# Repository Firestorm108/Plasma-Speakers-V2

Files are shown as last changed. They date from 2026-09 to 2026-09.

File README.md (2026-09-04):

# Plasma-Speakers-V2

Dual flyback transformers that produce audio through the modulation of high frequency plasma arcs.

# What is it?
This is version two of my plasma speaker project (https://github.com/Firestorm108/Stereo-Plasma-Speaker). It produces arcs much larger than the previous version, and the heating of the MOSFETs is much lower. This is because it sort of combines two types of oscillating technologies. It uses the same principle of a ZVS driver, switching at zero volts for a great efficiency, but it is able to do this digitally instead of through analog components.

# Images

Screenshot 2026-09-03 at 11 55 16 PM

Screenshot 2026-09-03 at 11 56 20 PM

Screenshot 2026-09-04 at 12 08 57 AM
Screenshot 2026-09-04 at 12 09 14 AM

| Item | Price | Link |
| --- | ---: | --- |
| PCB + Assembly | $170 | JLCPCB |
| IRFP460 MOSFETs | $12 | [Amazon](https://www.amazon.com/ACEIRMC-Transistors-IRFP260N-N-Channel-IRFP260NPBF/dp/B0CGHP2LH6) |
| AC Cable | $7 | [Amazon](https://www.amazon.com/Standard-Electronics-Computer-Printer-Monitor/dp/B09VRLJD7J/) |
| 25A 24V PSU | N/A | Already Owned |
| Flyback Transformers (2) | $50 | [Amazon](https://www.amazon.com/TEAMWILL-Transformer-BSC24-39202-BSC26-N2137-BSC26-N2138/dp/B09P2Y9X9F/) |
| **Total** | **$239** | |

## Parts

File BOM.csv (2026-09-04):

Item | Price | Link
PCB + Assembly | $170 | JLCPCB
IRFP460 MOSFETs | $12 | https://www.amazon.com/ACEIRMC-Transistors-IRFP260N-N-Channel-IRFP260NPBF/dp/B0CGHP2LH6
AC Cable | $7 | https://www.amazon.com/Standard-Electronics-Computer-Printer-Monitor/dp/B09VRLJD7J/
25A 24V PSU | N/A | Already Owned
Flyback Transformers (2) | $50 | https://www.amazon.com/TEAMWILL-Transformer-BSC24-39202-BSC26-N2137-BSC26-N2138/dp/B09P2Y9X9F/
Total: | $239

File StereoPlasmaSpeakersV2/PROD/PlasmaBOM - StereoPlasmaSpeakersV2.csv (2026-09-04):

Id | Designator | Footprint | Quantity | Comment | Supplier and ref
1 | AV1, AV2 | CONN-TH_AV-5 | 2 | AV-5
2 | C1 | C_1206_3216Metric | 1 | 47uF
3 | C2, C3, C6, C7 | C_1206_3216Metric | 4 | 10uF
4 | C4, C8 | C_1206_3216Metric | 2 | 100nF
5 | C5, C9, C11, C14 | C_1206_3216Metric | 4 | 10nF
6 | C10, C13 | C_1206_3216Metric | 2 | 4.7nF
7 | C12, C15 | C_1206_3216Metric | 2 | 1uF
8 | C17, C18, C19, C20, C21, C22 | CAP-TH_L12.0-W6.0-P10.00-D0.6-A | 6 | C322J10458P40001
9 | D1, D2, D3 | LED_1206_3216Metric | 3 | LED
10 | D4, D5 | D_SOD-123 | 2 | 1N4148W
11 | J1 | CONN-TH_P10.16_KF135T-10.16-2P | 1 | 24V 25A
12 | J2 | CONN-TH_P10.16_KF135T-10.16-2P | 1 | Primary_1
13 | J3 | CONN-TH_P10.16_KF135T-10.16-2P | 1 | Primary_2
14 | Q2, Q4 | TO-247-3_Vertical | 2 | IRFP260N
15 | Q3, Q5 | SOT-89-3 | 2 | BCX51
16 | R1 | R_1206_3216Metric | 1 | 2.2K
17 | R2, R9, R11, R17, R20, R23 | R_1206_3216Metric | 6 | 1K
18 | R3, R10, R25, R27 | R_1206_3216Metric | 4 | 470
19 | R4, R6, R13, R14 | R_1206_3216Metric | 4 | 100
20 | R5, R8, R12, R15 | R_1206_3216Metric | 4 | 10K
21 | R7, R16 | R_1206_3216Metric | 2 | 220
22 | R18, R21 | R_1206_3216Metric | 2 | 33K
23 | R19, R22 | R_1206_3216Metric | 2 | 3.3K
24 | R24, R26 | R_1206_3216Metric | 2 | 270
25 | RV1, RV2 | RES-ADJ-TH_3296W | 2 | 5K
26 | SW1, SW2 | SW_Push_SPST_NO_Alps_SKRK | 2 | Test
27 | U1 | TO-263-3_L8.6-W10.2-P2.54-LS14.4-BR | 1 | LM7812SX/NOPB
28 | U2, U3 | SOIC-8_L5.0-W4.0-P1.27-LS6.0-BL | 2 | LM311
29 | U4, U5 | SOIC-8_3.9x4.9mm_P1.27mm | 2 | NE555D

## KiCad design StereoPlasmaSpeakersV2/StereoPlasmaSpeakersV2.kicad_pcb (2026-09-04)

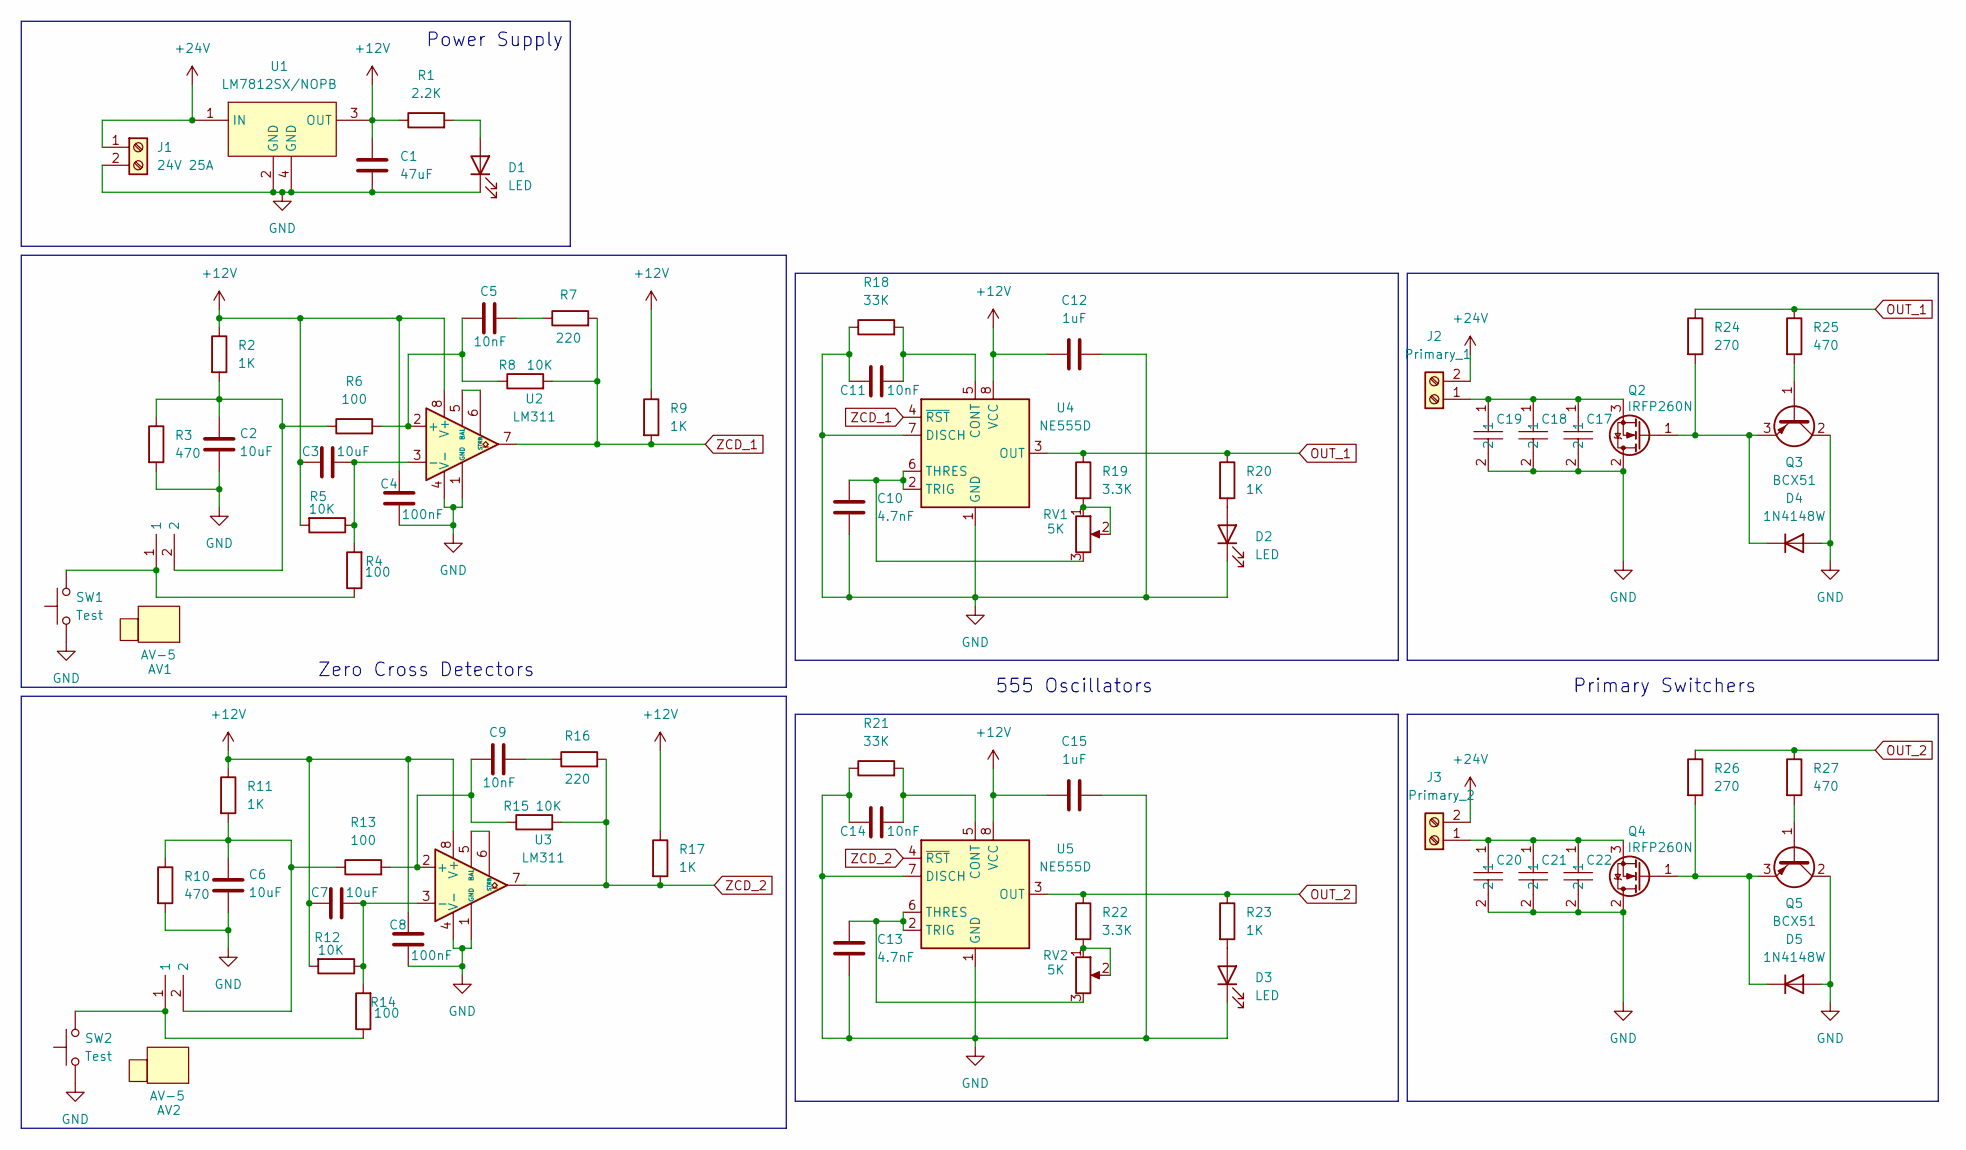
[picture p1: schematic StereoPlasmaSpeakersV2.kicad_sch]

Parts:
AV1, AV2: AV-5; CONN-TH_AV-5; MPN AV-5; LCSC Part C18080
C1: 47uF; C_1206_3216Metric
C2, C3, C6, C7: 10uF; C_1206_3216Metric
C4, C8: 100nF; C_1206_3216Metric
C5, C9, C11, C14: 10nF; C_1206_3216Metric
C10, C13: 4.7nF; C_1206_3216Metric
C12, C15: 1uF; C_1206_3216Metric
C17, C18, C19, C20, C21, C22: C322J10458P40001; CAP-TH_L12.0-W6.0-P10.00-D0.6-A; MPN C322J10458P40001; LCSC Part C46638903
D1, D2, D3: LED; LED_1206_3216Metric
D4, D5: 1N4148W; D_SOD-123
J1: 24V 25A; CONN-TH_P10.16_KF135T-10.16-2P
J2: Primary_1; CONN-TH_P10.16_KF135T-10.16-2P
J3: Primary_2; CONN-TH_P10.16_KF135T-10.16-2P
Q2, Q4: IRFP260N; TO-247-3_Vertical
Q3, Q5: BCX51; SOT-89-3
R1: 2.2K; R_1206_3216Metric
R2, R9, R11, R17, R20, R23: 1K; R_1206_3216Metric
R3, R10, R25, R27: 470; R_1206_3216Metric
R4, R6, R13, R14: 100; R_1206_3216Metric
R5, R8, R12, R15: 10K; R_1206_3216Metric
R7, R16: 220; R_1206_3216Metric
R18, R21: 33K; R_1206_3216Metric
R19, R22: 3.3K; R_1206_3216Metric
R24, R26: 270; R_1206_3216Metric
RV1, RV2: 5K; RES-ADJ-TH_3296W
SW1, SW2: Test; SW_Push_SPST_NO_Alps_SKRK
U1: LM7812SX/NOPB; TO-263-3_L8.6-W10.2-P2.54-LS14.4-BR; MPN LM7812SX/NOPB; LCSC Part C2870248
U2, U3: LM311; SOIC-8_L5.0-W4.0-P1.27-LS6.0-BL
U4, U5: NE555D; SOIC-8_3.9x4.9mm_P1.27mm

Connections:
+12V: C1.1, C3.1, C4.1, C7.1, C8.1, C12.2, C15.2, R1.1, R2.1, R5.2, R9.1, R11.1, R12.2, R17.1, U1.3 (OUT), U2.8 (V+), U3.8 (V+), U4.8 (VCC), U5.8 (VCC)
+24V: J1.1, J2.2, J3.2, U1.1 (IN)
GND: C1.2, C2.2, C4.2, C6.2, C8.2, C10.2, C11.1, C12.1, C13.2, C14.1, C15.1, C17.2, C18.2, C19.2, C20.2, C21.2, C22.2, D1.1 (K), D2.1 (K), D3.1 (K), D4.2 (A), D5.2 (A), J1.2, Q2.2 (D), Q3.2 (C), Q4.2 (D), Q5.2 (C), R3.2, R10.2, R18.1, R21.1, SW1.1, SW2.1, U1.2 (GND), U1.4 (GND), U2.1 (GND), U2.4 (V-), U3.1 (GND), U3.4 (V-), U4.1 (GND), U4.7 (DISCH), U5.1 (GND), U5.7 (DISCH)
unnamed: AV1.1, R4.1, SW1.2
unnamed: AV1.2, C2.1, R2.2, R3.1, R6.1
unnamed: AV2.1, R14.1, SW2.2
unnamed: AV2.2, C6.1, R10.1, R11.2, R13.1
unnamed: C5.2, R7.1
unnamed: C9.2, R16.1
unnamed: D1.2 (A), R1.2
unnamed: D2.2 (A), R20.2
unnamed: D3.2 (A), R23.2
unnamed: D4.1 (K), Q2.1 (G), Q3.3 (E), R24.2
unnamed: D5.1 (K), Q4.1 (G), Q5.3 (E), R26.2
unnamed: C17.1, C18.1, C19.1, J2.1, Q2.3 (S)
unnamed: C20.1, C21.1, C22.1, J3.1, Q4.3 (S)
unnamed: Q3.1 (B), R25.2
unnamed: Q5.1 (B), R27.2
unnamed: R19.2, RV1.1, RV1.2
unnamed: R22.2, RV2.1, RV2.2
unnamed: C5.1, R6.2, R8.1, U2.2 (+)
unnamed: C3.2, R4.2, R5.1, U2.3 (-)
unnamed: U2.5 (BAL), U2.6 (STRB)
unnamed: C9.1, R13.2, R15.1, U3.2 (+)
unnamed: C7.2, R12.1, R14.2, U3.3 (-)
unnamed: U3.5 (BAL), U3.6 (STRB)
unnamed: C11.2, R18.2, U4.5 (CONT)
unnamed: C10.1, RV1.3, U4.2 (TRIG), U4.6 (THRES)
unnamed: C14.2, R21.2, U5.5 (CONT)
unnamed: C13.1, RV2.3, U5.2 (TRIG), U5.6 (THRES)
OUT_1: R19.1, R20.1, R24.1, R25.1, U4.3 (OUT)
OUT_2: R22.1, R23.1, R26.1, R27.1, U5.3 (OUT)
ZCD_1: R7.2, R8.2, R9.2, U2.7, U4.4 (~RST)
ZCD_2: R15.2, R16.2, R17.2, U3.7, U5.4 (~RST)

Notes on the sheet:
Power Supply
Primary Switchers
Zero Cross Detectors
555 Oscillators

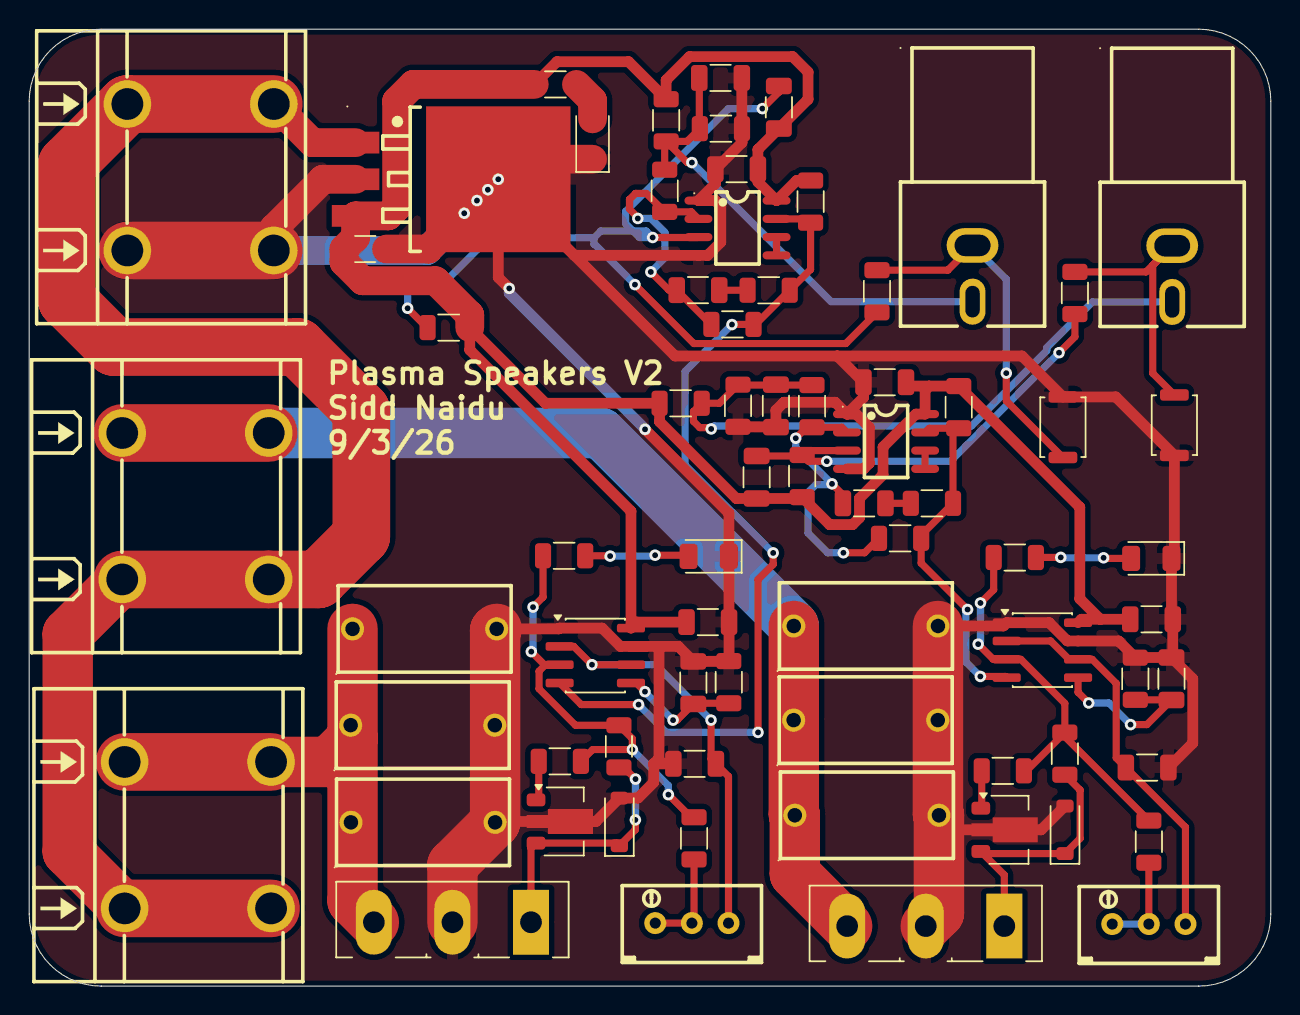
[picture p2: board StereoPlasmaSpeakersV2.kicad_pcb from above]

Board: 2 copper layers, 86.1 x 66.4 mm, 71 parts (0 on the bottom side), 34 nets.
